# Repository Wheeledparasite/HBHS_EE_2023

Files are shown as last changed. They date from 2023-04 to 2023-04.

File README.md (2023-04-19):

# Huntington Beach High Automotive Engineering Club - UCI Energy Invitational 2023
Welcome to the GitHub repository for the HBHS entry in the 2023 [UCI Energy Invitational Competition](https://vitallink.org/program/energy-invitational/). This project involves building an electric vehicle to compete in an efficiency race. The goal is to create a vehicle that can travel the furthest distance with the least amount of energy, in the shortest amount of time.

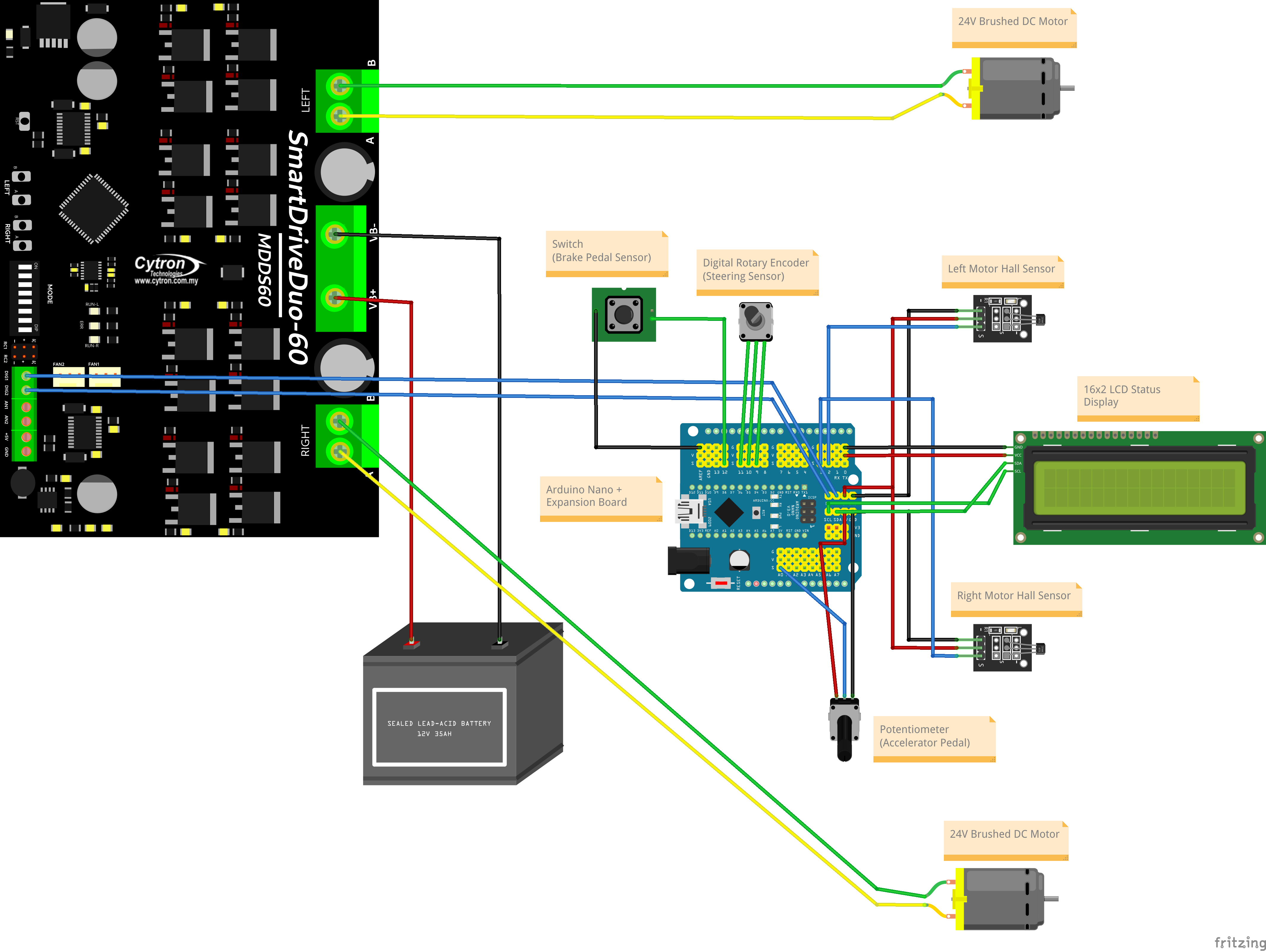
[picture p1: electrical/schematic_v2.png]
Schematic


## Project Overview
The project consists of several components, including:

Electrical schematics: These documents show the wiring and connections between the various components in the vehicle, including the motor controller, batteries, and sensors. They were created using [Fritzing](https://fritzing.org/).

Code: The code controls the various systems in the vehicle, including the motor, throttle, brakes, and steering. It is written in C++ and runs on an Arduino Nano microcontroller.

CAD drawings: The CAD drawings show the design of the vehicle, including the chassis, body, and other components. They were created using [FreeCAD](https://www.freecad.org/).

Bill of materials: The bill of materials lists all the components used in the vehicle, including part numbers, quantities, and prices.

## Components of this Repository
This repository contains various components that we worked on during the 2023 competition:

1. CAD drawings of various components and parts we needed to manufacture.
2. Electrical Schematics and Block Diagrams
3. Arduino Software for Vehicle #1: Utilizing the [Cytron SmartDrive MDDS60](https://www.cytron.io/p-60amp-7v-45v-smartdrive-dc-motor-driver-2-channels) Motor Driver.
4. Arduino Software for Vehicle #2: Utilizing the [Cytron MD30C Motor Driver](https://www.cytron.io/c-motor-and-motor-driver/c-motor-driver/p-30amp-5v-30v-dc-motor-driver).
5. Python Software used to perform preliminary performance analysis.

## Contributing
If you have suggestions or improvements for this project, feel free to submit a pull request or open an issue. While we mainly focus on contributions from the Automotive Engineering club members of Huntington Beach High School, we are willing to accept contributions from the general public.

## Credits
This project was created by the 2023 Huntington Beach High School [Automotive Engineering Club](https://hbhs.bytethug.com/) and is licensed under the GPL-3 license. Special thanks to the UCI Energy Invitational organizers and sponsors for creating this competition and promoting energy-efficient transportation.

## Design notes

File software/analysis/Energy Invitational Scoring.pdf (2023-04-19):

2023 Energy Invitational Score Calculations (TASK)

Purpose: To calculate the optimal vehicle speed that will result in the largest score. Knowing the optimal speed will allow us to optimize the vehicle for that speed.

Who? → The Electrical and Software Team

Formula: TOTAL SCORE = 10, 000, 000 / (WattHours * seconds)

Discussion: The two variables can be calculated as follows

1. seconds = Track Distance / velocity
2. Watt-Hours is a unit of energy and is used to measure the amount of work performed:

Work Performed = (a) Work to bring vehicle up to final velocity + (b) Work to overcome air resistance + (c) Work to overcome rolling resistance

We will not consider slowing down for corners, etc. We will just look at the simple scenario to bring the vehicle up to a velocity and to maintain that velocity for the entire distance of the track (1000 meters?).

There are two phases where we need to calculate work done:

### 1. Acceleration Phase:

Work = Work to accelerate vehicle to final velocity + Work to overcome drag while accelerating

Work of Acceleration Phase = ½ mv

2 +

0

x
∫ F
d
- dx

### 2. Constant Velocity Phase

Work = Work to overcome drag at final velocity

To simplify the calculations at the expense of a little bit less accuracy, we ignore the integral term of the acceleration phase and calculate work to overcome drag over the entire distance of the track as follows:

Total Work = work to accelerate vehicle + work to overcome drag at final velocity

a) Work to accelerate vehicle to final velocity:

E = 1/2 * m * v

2

b) Work to overcome air resistance:

Force of Drag (in newtons) Fd = cd * ½ * ρ * v

2 * A

Where:
Fd = Force of Drag (newtons) cd = drag coefficient (est 0.42) ρ = density of flue (1.2 kg/m³ for air at NTP)
v = final velocity (m/s)
A = frontal area of the body (m²

) - [estimated 1.4m²
for 2022 vehicle]

Work to overcome drag (in joules or newton-meters) Wd = Fd * d

Where:
Wd = work done to overcome drag (in joules)
d = distance in meters
c) Work to counteract rolling resistance:
Lets ignore rolling resistance for now (it won’t make much of a difference and like above, it exponentially increases with velocity)

TOT WORK = Work to bring vehicle to velocity + Work to overcome air resistance

To convert to watt-hours:
Watt-Hours = Total Work (in joules) * 0.00027777777777778

Notes:
Let's look at the scoring formula again:
TOTAL SCORE = 10, 000, 000 / (WattHours * seconds)

The energy requirements (Watt-Hours) increase exponentially with velocity, while the seconds term decreases linearly with velocity. Therefore, just a quick look at the formula seems to indicate that the lowest velocity will result in the highest score. Could this be why there were some 2022 teams that were driving very slow (ie. 5mph)?

You could add rolling resistance and motor + drivetrain inefficiencies, but I don’t think it will make a difference.

TASK → SOFTWARE TEAM
1. Confirm the above assumptions (could check with Mr. Egan)
2. Write a computer program to plot the score vs velocity graph so we can validate and quantify expected score at a particular speed.

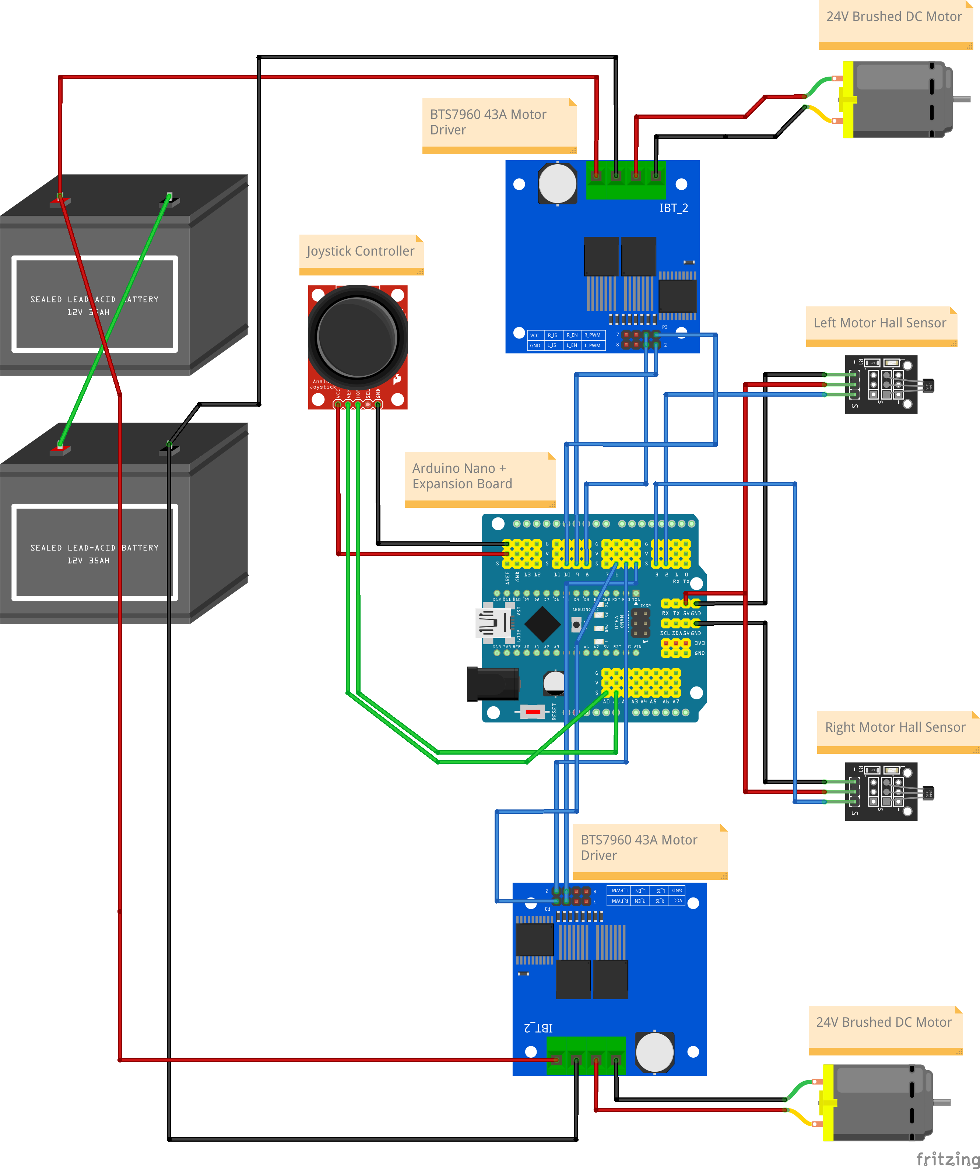
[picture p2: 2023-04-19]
electrical/schematic_v1.png

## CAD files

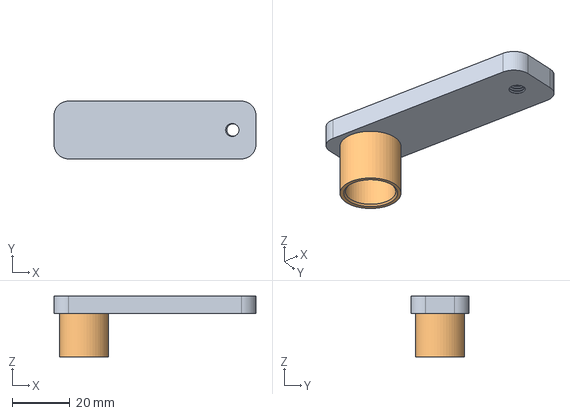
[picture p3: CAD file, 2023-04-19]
CAD/FreeCAD/steering_jig.FCStd
70.0 x 20.0 x 21.0 mm

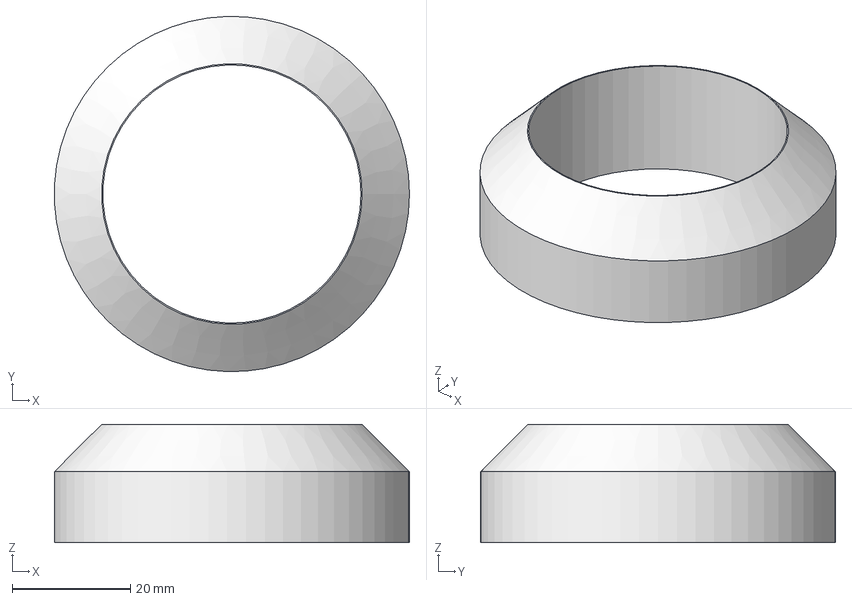
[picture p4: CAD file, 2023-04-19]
CAD/FreeCAD/steering_collar.FCStd
60.0 x 60.0 x 20.0 mm

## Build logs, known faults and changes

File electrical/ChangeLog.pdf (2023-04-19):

Electronics Changelog

Version 1.0
- 16Mhz Arduino NANO
- 3 Hardware Timers (Timer0, Timer1 and Timer2)
- 1 UART (serial port)
- 6 PWM Pins (8-bit)
- 2 Interrupt Pins (Pin 2 & Pin 3)
- 2 Kb RAM
- 32 Kb Flash ROM
- (2) BTS7960 43A Motor Drivers
- Input from PS2 Style Joystick
- Hall Effect Sensors for wheel encoders (speed sensor)

Limitations of Version 1.0 Hardware
After building the 1.0 electronics test platform, we quickly determined there were some limitations of using such a slow 8-bit processor. First, because each of the BTS7960 motor drivers required 2 PWM signals, we needed a total of 4 PWM outputs. Using 4 PWM pins on the Arduino Nano meant that both TIMER0 and TIMER1 were being used to generate PWM signals and we only had TIMER2 left. We are using Timer2 set to 500ms to average the wheel encoder counts. Also, we have two HALL effect sensors we are using to measure wheel speed, these use up both Interrupt pins, leaving us with no free external interrupt pins in case we want to measure something else using interrupts. Two PID controllers manage motor speed based upon user input and measured speed.

Version 2.0:
- 16Mhz Arduino NANO
- 3 Hardware Timers (Timer0, Timer1 and Timer2)
- 1 UART (serial port)
- 6 PWM Pins (8-bit)
- 2 Interrupt Pins (Pin 2 & Pin 3)
- 2 Kb RAM
- 32 Kb Flash ROM
- (1) Cytron SmartDuo 60A Dual Channel Motor Driver (supports UART)
- Input from Accelerator Pedal + Steering Wheel
- (2) Temperature Sensors
- Hall Effect Sensors for wheel encoders (speed sensor)

Notes on Version 2.0 Hardware
The biggest change to this revision is the change from the generic motor drivers in V1 to the Cytron 60A Dual Driver in V2. This new motor driver allows serial communication (UART), allowing us to free up another TIMER in the Arduino, by removing the need for PWM, which will allow us to smoothly apply acceleration and deceleration, preventing the jerky movements we experienced in Version 1.0.

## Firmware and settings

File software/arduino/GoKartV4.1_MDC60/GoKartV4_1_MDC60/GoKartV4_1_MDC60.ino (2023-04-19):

/*
 * Author: Lucas Ruebsamen
 * Date: December 28, 2021
 * 
 * Version 1.1 - Updated Jan 14, 2022
 * Version 1.4 - Updated Feb 9, 2022
 * Version 3.0 - Updated March 16, 2022
 * Version 3.1 - Updated April 20, 2022
 * Version 4.1 - Updated April 10, 2023
 * Version 4.2 - Updated April 12, 2023
 * 
 * Changelog:
 * 1.0 - Original Version using Differential Steering
 * 1.1 - Remove reverse ability
 * 1.2 - Interrupt to count wheel rotation sensors (hall effect sensor)
 * 1.3 - Implement PID motor control
 * 1.4 - 500ms Timer2 interrupt to average wheel encoder counts.
 * 3.0 - Move to Cytron Driver board (serial) and steering encoder
 * 3.1 - Brake on Startup (Safety Feature)
 * 3.2 - Soft Acceleration
 * 4.1 - 4-line LCD, improved soft accelration, changed potentiometer values
 * 4.2 - Brake paddle, reverse w/ brake
 * 
 * Notes: Differential steering control using two BTS7960 motor drivers
 *        driving two 250W Scooter motors.
 * 
 * Differential Steering Library: https://github.com/edumardo/DifferentialSteering
 * LCD Library: https://github.com/mrkaleArduinoLib/LiquidCrystal_I2C
 * PID Lbirary: https://github.com/imax9000/Arduino-PID-Library
 */

// SmartDriveDuo-60 Simplied Serial Mode (115200 baud) DIP SW SETTINGS:
// 11011100

/*
 * Timer0 - used for millis() micros() delay()… and is on pin 5, 6
 * Timer1 - 16bit timer is on pin 9, 10
 * Timer2 - 8bit timer is on pin 3, 11
 * 
 */

#include <Wire.h> 
#include <LiquidCrystal_I2C.h>
//#include "QuickPID.h"
//#include <MsTimer2.h>
//#include "DifferentialSteering.h"
#include <Encoder.h>

//#define PIDCONT

// PWM PINS on NANO: 3,5,6,9,10,11
// INTERRUPT PINS ON NANO: 2,3

// STEERING SENSOR (Rotary Encoder)
const uint8_t STEER_A = 7;
const uint8_t STEER_B = 8;
const uint8_t STEER_SW = 4;

//Pedal sensor pin
const uint8_t PEDAL = A0;

//turbo pin
const uint8_t TURBO = 9;

//power switch
const uint8_t POWER = 6;

//direction switch
const uint8_t DIRSW = 5;

//brake light
const uint8_t BRAKELIGHT = 10;

const uint8_t MAXIMUM = 40;

// differential steering
//const int brakeThreshold = 0;
//const int fPivYLimit = 32;  // 0 - 127 (A greater value will assign more of the joystick's range to pivoting) - default 32
//DifferentialSteering DiffSteer;

// instantiate our objects
LiquidCrystal_I2C lcd(0x27,20,4);  // set the LCD address to 0x27 for a 16 chars and 4 line display
Encoder steerEncoder(STEER_A, STEER_B);

const unsigned int sampleTime = 256;  // LCD UPDATE INTERVAL
const unsigned int accelTime = 500;   // ACCEL UPDATE INTERVAL
unsigned int MAX_POWER = 32;
unsigned long lastMillis = 0;
unsigned long lastMillisAccel = 0;
volatile uint16_t avgLeft = 0;
volatile uint16_t avgRight = 0;
int pedalPos;
int desiredPedalPos = 0;

void coast() {
 if (desiredPedalPos == 0 && pedalPos > 0) {
    if (desiredPedalPos > pedalPos) {
      pedalPos = desiredPedalPos;
  } else {
    int antidiff = floor( ((float)(desiredPedalPos + pedalPos))*(0.2f) );

    //if (pedalPos > 26) {
    //  diff = 1; // slow down acceleration at top speed.
    //}
    pedalPos -= antidiff;
    if (pedalPos < desiredPedalPos) {
      pedalPos = desiredPedalPos;
    }
    // check against max power
    //if (pedalPos > MAX_POWER) {
    //  pedalPos = MAX_POWER;
    //}
  }
 }
}


// Update Acceleration
void updateAccel()
{
  if (desiredPedalPos < pedalPos) {
    pedalPos = desiredPedalPos;
  } else {
    int diff = ceil( ((float)(desiredPedalPos - pedalPos))*(0.2f) );

    if (pedalPos > 26) {
      diff = 1; // slow down acceleration at top speed.
    }
    pedalPos += diff;
    if (pedalPos > desiredPedalPos) {
      pedalPos = desiredPedalPos;
    }
    // check against max power
    if (pedalPos > MAX_POWER) {
      pedalPos = MAX_POWER;
    }
  }
}

// Run Once - Setup
void setup()
{
  Serial.begin(115200);
  // setup pins for speed sensors
  //pinMode(R_SEN, INPUT);
  //pinMode(L_SEN, INPUT);

  // pin for rotary switch
  pinMode(STEER_SW, INPUT_PULLUP);

  // setup pin for analog accelerator pedal
  pinMode(PEDAL, INPUT);
  pinMode(TURBO, INPUT_PULLUP);

  // setup pin for Power Switch
  pinMode(POWER, INPUT_PULLUP);

  pinMode(DIRSW, INPUT_PULLUP);
  pinMode(BRAKELIGHT, OUTPUT);

  // set initial speed to 0 for motor driver
  Serial.write(0b01000000);
  Serial.write(0b11000000);
  pedalPos = 0;
  desiredPedalPos = 0;
  
  lcd.init();   // initialize the lcd 
  lcd.backlight();
  lcd.clear();
  lcd.print("GoKart v4.1");
  lcd.setCursor(0,1);
  lcd.print("Lucas Ruebsamen");
  delay(1000);
  lcd.clear();
  //DiffSteer.begin(fPivYLimit);
}

long positionSteering = -999;
long lastPosition = 0;
bool turboMode = true;
bool powerSwitch = false;
uint8_t direction = 1;  // current direction -- 1 is forward, 0 is reverse
uint8_t dirSwitch = 1;  // direction switch

// 0 = 0v to 1023 = 5v
// we need 0 - 127 
void loop()
{
  char sVal[5];

  // read steering encoder
  positionSteering = steerEncoder.read();

  if (positionSteering > lastPosition) {
    MAX_POWER++;
    lastPosition = positionSteering;
    if (MAX_POWER >= MAXIMUM  ) {
      MAX_POWER = MAXIMUM;
    }
  
  } else if (positionSteering < lastPosition) {
    MAX_POWER--;
    lastPosition = positionSteering;
    if (MAX_POWER <= 7) {
      MAX_POWER = 7;
    }
    
  }
  
  // reset encoder on button push
  if(digitalRead(STEER_SW) == LOW) {
    steerEncoder.write(0);
    MAX_POWER = 32;
  }

  // read accelerator pedal (185 - 855)
  // Note: MDC60 Cytron Driver - Serial mode takes 6 bit speed input (0 - 63)
  desiredPedalPos = analogRead(PEDAL);
  //desiredPedalPos = map(desiredPedalPos, 28, 63, 0, 63);

  // brake enabled
  if (desiredPedalPos <= 2) {
    desiredPedalPos = 0;
    digitalWrite(BRAKELIGHT, HIGH);
    direction = dirSwitch;
  } else {
    digitalWrite(BRAKELIGHT, LOW);
  }

  if (desiredPedalPos >= 63) {
    desiredPedalPos = 63;
  }
  
  //read dir switch
  if (digitalRead(DIRSW) == LOW) {
    dirSwitch = 1;  // forward
  } else {
    dirSwitch = 0; // reverse
  }
  
  // read turbo switch
  if (digitalRead(TURBO) == LOW) { 
    turboMode = true;
    MAX_POWER = 63;
  } else {
    //desiredPedalPos = floor(desiredPedalPos * 0.65);
    turboMode = false;
  }

  if (digitalRead(POWER) == LOW) {
    powerSwitch = false;
  } else {
    powerSwitch = true;
  }

  // if we want to go slower, immediately reduce speed
  if (desiredPedalPos < pedalPos) {
    pedalPos = desiredPedalPos;
  }
  
  // take pedal position and steering position and compute motor output

  // compute left motor
  unsigned char leftVal = pedalPos & 0b00111111;
  leftVal = (leftVal | 0b00000000) | (direction << 6);
  // compute right motor
  unsigned char rightVal = pedalPos & 0b00111111;
  rightVal = (rightVal | 0b10000000) | (direction << 6);

  // set motor direction
  //if (direction) {
  //  leftVal = leftVal | (1 << 6);
  //  rightVal = rightVal | (1 << 6);
  //}

  // Write serial data to motor driver
  if (powerSwitch) {
    // power is on, control motors
    Serial.write(leftVal);
    Serial.write(rightVal);
  } else {
    // power is off, motors disabled
    Serial.write(0b01000000);
    Serial.write(0b11000000);
  }

  // HANDLE ACCELERATION UPDATES HERE
  if (millis() - lastMillisAccel >= accelTime) {
    updateAccel();
    coast();
    lastMillisAccel = millis();
  }

  // HANDLE LCD UPDATES HERE
  if (millis() - lastMillis >= sampleTime) {
    // 500ms has elapsed since last lcd update, time to update again
    lcd.setCursor(0,0); // col 0, row 0
    if (powerSwitch) {
      lcd.print("S: ");
      sprintf(sVal, "%+04d", (int)MAX_POWER);
      lcd.printstr(sVal);
  
      lcd.setCursor(8,0); // col 0, row 1
      lcd.print("P: ");
  
      if (turboMode == true) {
        sprintf(sVal,"%+04d*", (int)pedalPos);
      }else {
        sprintf(sVal,"%+04d ", (int)pedalPos);
      }
      lcd.printstr(sVal);
  
      lcd.setCursor(0,1); // col 0, row 1
      lcd.print("D: ");
      //lcd.print(xValue);
      //sprintf(sVal,"%+04d", (int)pedalPos);
      if (direction == 1) {
        sprintf(sVal,"rev");
      } else {
        sprintf(sVal, "for");
      }
      
      lcd.printstr(sVal);
  
      lcd.setCursor(8,1);   // col 8, row 1
      lcd.print("V: ");
      sprintf(sVal,"%+04d", (int)desiredPedalPos);
      lcd.printstr(sVal);
    } else {
      lcd.print("Pow     Off");
    }
    lastMillis = millis();
  }
}

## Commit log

2023-04-19 initial commit for 2023
    [lucas_gokart.fzz, steering_collar.FCStd, steering_jig.FCStd]
2023-04-19 arduino code for Cytron MD30C
2023-04-19 Arduino code for Cytron MDC60
2023-04-19 add schematic
